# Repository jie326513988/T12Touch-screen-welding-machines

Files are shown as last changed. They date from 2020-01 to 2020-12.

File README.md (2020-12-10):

# 请注意！电流采样电路使用方法错误，电流不准，但不影响其他功能使用，修正版本正在制作！
# T12触屏焊台-Atmega328p-au核心
* 使用了[LCDWIKI_KBV、LCDWIKI_GUI、TouchScreen库](http://www.lcdwiki.com/zh/2.4inch_Arduino_Display)，感谢[LCDWIKI](http://www.lcdwiki.com)。
* Arduino Nano，触摸屏，降压电路都为模块拔插式，其他部分电路为贴片焊接，方便新手。
* 从30℃加热到400℃需16-20秒，稳定跳动温度±1℃，适配深圳头。
* 观看视频https://www.bilibili.com/video/av83184959
* 基本功能已经完善:
    *  触摸调节温度，30-400℃，3段一键温度
    *  使用虚拟数字键盘
    *  可菜单调节 单神经元PID，自主学习，控制精确（新增）
    *  可菜单调节 烙铁的休眠时间和休眠温度
    *  独立的室温采集芯片用于自动补偿T12温度
    *  屏幕校准，开机长按屏幕进入校准界面（新增）
    *  到达温度提示声，唤醒提示声，休眠提示声，触摸提示声（新增）
    *  eeprom保存数据
    *  INA19硬件真实电流采样
    *  内置看门狗防止死机引起意外
    *  未接手柄报警、烙铁温度超出读取范围报警、高压报警、过流报警、机内温度高温报警（新增）
    *  使用3项式公式计算的温度曲线，使用外部PT100探头精准调教的温度曲线
####   必读注意！！！
####   1：nano的bootloader使用看门狗有几率卡死，uno正常，先将nano刷成uno的引导再烧录程序
####   2：为了加快触摸的读取速度，需要修改以下内容，但有非常小的几率会误触
####      打开TouchScreen.cpp ,修改NUMSAMPLES 后面的数值为 20
####   3:一定要先刷入EEPROM，说明看程序第232行，首次使用记得校准屏幕（开机时长按屏幕，听到连续的提示声放开）
####   4:电流采样改用INA193芯片
####   5:使用可调DC-DC降压模块，调至6.5V使用，6.5V输入至nano自带线性稳压得到稳定的5V电压
####   6:不要更改t12_pwm_pin（nano 10号脚，2560 12号脚），此脚连接了内部定时器1的B通道，该通道需要输出61HZ和2048级pwm，内部定死，改了会有难以预料的后果
####   7:如果内存溢出，请看第2项说明改了就不会了
#### ---------------------------------------------------------------------------------------------
###  最新更新说明 V1.2.6 - 2020-09-24
#### 新增未接手柄报警、烙铁温度超出读取范围报警、高压报警、过流报警、机内温度高温报警
#### 当出现任意一个报警，主界面就会显示Error
#### 修复校准屏幕有几率无法保存数据的BUG
#### 再次校准温度曲线,使用3项式
#### 移除手动补偿设置(发现没什么用)
#### ---------------------------------------------------------------------------------------------
2020-09-22<br> v1.2.5 PMOS版本-需要UNO引导,修复手动补偿的BUG,修复pwm的一个BUG,使用PT100重新校准了温度曲线，缩小误差,开机前读取255次电压和室温<br>
2020-09-18<br> v1.2.4 PMOS版本-需要UNO引导,PWM控温精度改为2048级,加快超调回正时间,压榨内存<br>
2020-09-04<br> v1.2.3-仅限UNO引导使用,PID控温算法升级成“单神经元PID”，能自主学习以适配不同的刀头（同一厂家）和更加精准的控温。<br>
2020-09-02<br> v1.2.2-仅限UNO引导使用,修改温度显示策略，当温度稳定在10℃以内时，则显示每5次温度采集的平均温度，新增到达设定温度的提示声，取消从设置界面进入屏幕校准界面，只能从开机时长按屏幕任意地方进入并添加校准成功或失败的提示。<br>
2020-09-01<br> v1.2.1-仅限UNO引导使用,优化T12测量温度算法，使用睡眠模式进行ADC降噪读取，新增开机长按屏幕进入校准界面。<br>
2020-08-20<br> v1.2.0 PMOS版本-仅限UNO引导使用，新加手动温度补偿的功能，因nano内存不足需要刷成uno才能使用此版本。<br>
2020-07-12<br> v1.1.1 PMOS版本-Nano UNO可用，优化室温补偿的算法，优化读取电流的算法，优化键盘的算法，增加贴手感响应速度，新增开机读取电压和室温，重新测量了T12的温度曲线。<br>
2020-05-10<br> PMos版本已经测试完毕，mos正常发热0-50度，不会高到吓人，测量室温的NTC改为tc1047芯片，3D打印的外壳也重新设计并上传了。<br>
2020-02-17<br> NMOS的版本不再更新，即现在的版本（程序0.84和PCB1.3、1.4）。电路将大改一次，改用PMOS管改善发热问题，改用运放加0.1R的电阻检测电流，丢弃垃圾电流芯片。核心、5v电源和屏幕依旧使用拔插式。<br>
2020-02-17<br> v0.84，修改了主界面和设置界面的布局，使其更加对称顺眼。<br>
2020-02-14<br> V0.83，PWM输出修改成相位和频率校正模式，占空比控制精度提升一倍（0-511），并把频率降低至61HZ，烙铁发出的滴滴声大幅下降，频率提升到16khz时烙铁的滴滴声彻底听不见但MOS管发热严重并且控温效果差故不用高频PWM，喜欢滴滴声的可以用V0.82。<br>
2020-02-08<br>v0.82上线，增加测温的间隔，稍微提升一点加热效率。蜂鸣器的digitalWrite写法太占内存改为向端口输入引脚地址PINX写1来翻转状态bitWrite(PINB, 3, 1)，又节省74字节的内存，已用30606字节。修改了一下原理图和PCB，版本V1.4。优化sleep，当前温度低于设置的休眠温度时，到达休眠时间也存储当前温度。<br>
2020-02-07<br> 
上传原理图和能直接打板的文件，版本为V1.2。PCB我还想优化一下再放出，当然现在的版本也是可以用。<br>
2020-02-06<br>
v0.81 修复一个触屏校准的BUG。触摸加入一段限制算法降低屏幕自己点击自己的概率。电流测量加入一段判断算法，这样主界面就不会乱跳电流值了。<br>
2020-02-05<br>
v0.81版本，键盘触摸手感提升。<br>
2020-01-28 <br>
v0.81版本，修复了一个休眠的BUG，优化了温度测量，上传了3D打印件和成本清单。<br>
2020-01-24 <br>
v0.80版本，经过了8个小时的努力以及十几根头发的代价，又又又再一次压缩了Flash，还剩0.38%的空间，终于在nano/mini平台上加入屏幕校准功能。Uno平台还有5%，还可以美化一下UI。<br>
2020-01-22 <br>
v0.71版 新增坐标显示的开关，优化了flash，Mini还剩2%,Uno还剩7%,优化触摸读取速度，下一版本加入屏幕校准功能。<br>
2020-01-22 <br>
v0.7版，主界面新增一键到达设定温度的功能400/320/240。<br>
2020-01-20 <br>
v0.7版，增加软件过压过流过温保护，修正烙铁休眠唤醒不会回温的BUG，主界面美化一下，电路去掉了一个100欧的电阻，加热效率提升30%。<br>
2020-01-19 <br>
v0.6版上线，优化一些些内存，修改一下下菜单，增加了烙铁进入休眠的时间阈值和休眠的温度的菜单项，同样支持虚拟键盘修改数值和EEPROM。<br>
2020-01-16 <br>
优化了加热效率和控温稳定性。与设定值差10℃以上时，采样周期长，10℃以内，采样周期短。从30℃加热到260℃需15秒，稳定跳动温度3℃以内，通常为1℃。<br>
2020-01-14 <br>
终于实现了模拟键盘输入并可更改pid数值并储存在Eeprom中，有点小BUG但不影响使用。<br>
2020-01-13 <br>
初步实现稳定控温，从30℃加热到260℃需45秒，太久了。<br>
#### 引脚定义
LCD            D0  D1  D2  D3  D4  D5  D6  D7<br>
UNO/MINI/NANO  8   9   2   3   4   5   6   7<br>
LCDWIKI_KBV mylcd(ILI9341, A2, A1, 13, A0, 12);    //model,cs,cd,wr,rd,resett<br>
#define YP A2  // must be an analog pin, use "An" notation!<br>
#define XM A1  // must be an analog pin, use "An" notation!<br>
#define YM 9   // can be a digital pin<br>
#define XP 8   // can be a digital pin<br>
#define t12_temp_pin    A5                //T12温度读取引脚
#define sleep_pin       A3                //休眠状态读取引脚
#define ec_pin          A4                //电流读取引脚
#define volage_pin      A6                //电源电压读取引脚
#define tc1047_pin      A7                //tc1047读取引脚
#define t12_pwm_pin     10                //T12加热控制引脚
#define buzzer_pin      11                //蜂鸣器控制引脚
#### 电路简介
1.热电偶信号放大电路<br>
   使用AD8628（AD8605）轨到轨运算放大器，放大510倍，输入和输出均加有低通滤波器。<br>
2.功率输出电路<br>
   使用光耦和AOD4185场效应管组成的简单功率输出控制电路。<br>
3.检测电流电压电路<br>
   电流检测使用INA193芯片加0.05采样电阻，检测电流精度0.01A。<br>
   电压检测使用简单的分压电路测量，量程为0-42V，精度0.1V。<br>
4.供电电路<br>
   使用DCDC降压模块降至6.5V输入给Arduino Nano模块的VIN，上面有个5v稳压芯片，从而得到稳定的5V电压（要求纹波小，电压变动小）<br>
   24V电压使用的AC-DC24V4A成品电源，只要电压不超过24V电流大于3A即可。<br>
5.显示电路<br>
   使用2.4寸带触摸功能LCD屏幕模块，拔插式。提供显示功能和触摸功能。<br>
6.控制核心<br>
   使用Arduino Nano模块，核心为Atmel328p-AU,拔插式。<br>
 #### T12温度测量的方法及曲线拟合  
   * 因为每个厂家的T12内的热电偶都会有不同，所以不能使用常规的K/J/B型热电偶的分度表，除非T12厂家有给出
   * 准备一个能测500℃以上的测温设备，紧贴在T12的发热尖端，使用高温胶带绑紧
   * T12的热电偶电压经运算放大器510倍后再使用arduino测量T12的AD值，即T12热电偶的电压转换成数字量后的值
   * 使用pid算法加热T12，设置加热到的AD值为0-1000，每隔100个AD值记录一次温度
   * 记录得到AD值和对应的温度值后，使用EXCEL中的曲线拟合功能，拟合出一条三项式方程，此方程就是温度和AD关系的曲线
   * 有了此方程我们就能从T12当前的AD值计算出温度值
   * 本项目的方程 t12_temp = 0.0000001 * t12_ad * t12_ad * t12_ad - 0.00031185 * t12_ad * t12_ad + 0.64940017 * t12_ad + 15.945058;
   * 注意不同厂家的T12热电偶规格不同，更换厂家需要重新拟合一次曲线，本项目使用深圳头。
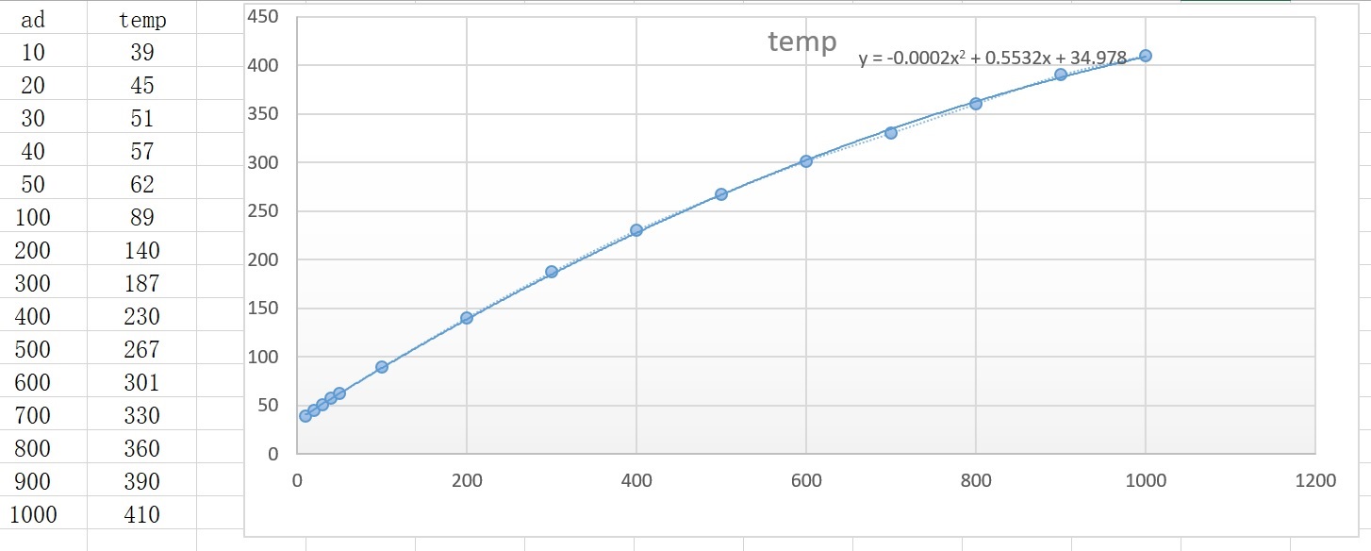
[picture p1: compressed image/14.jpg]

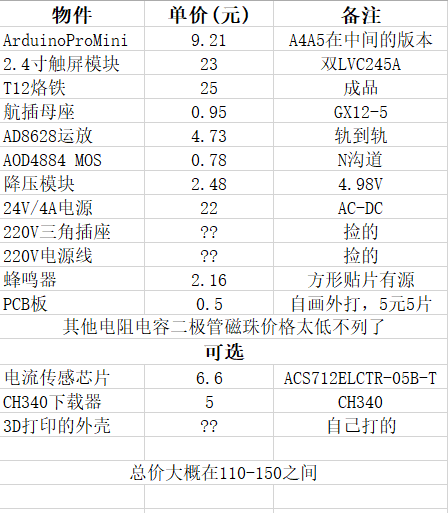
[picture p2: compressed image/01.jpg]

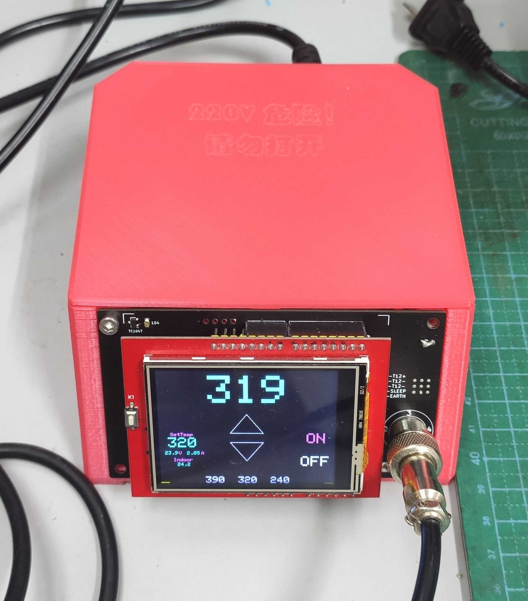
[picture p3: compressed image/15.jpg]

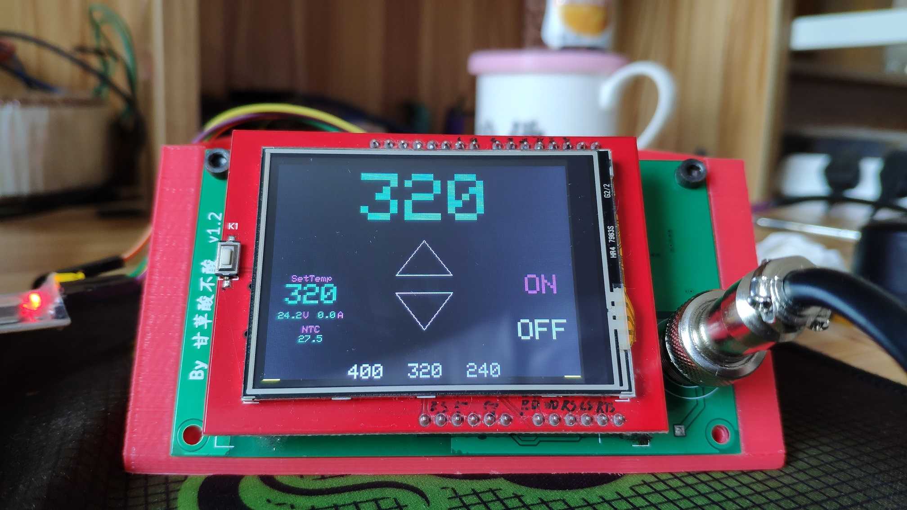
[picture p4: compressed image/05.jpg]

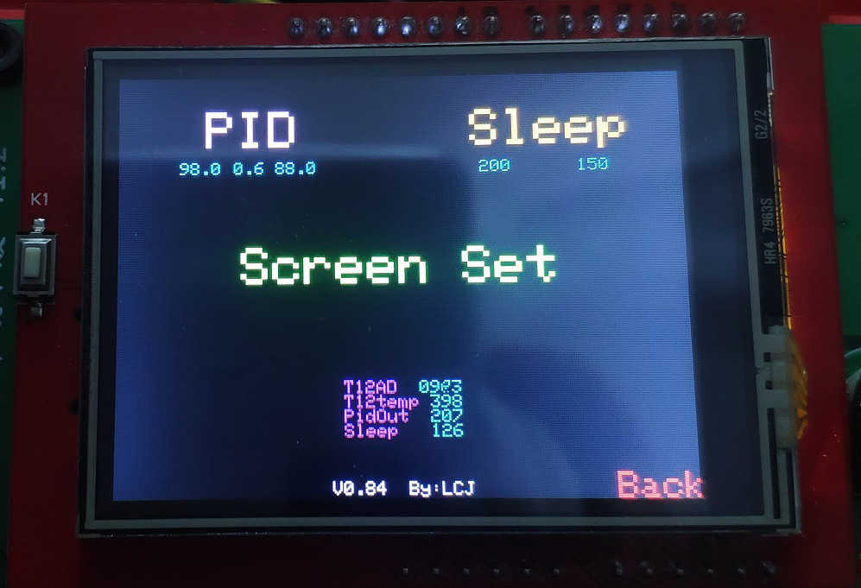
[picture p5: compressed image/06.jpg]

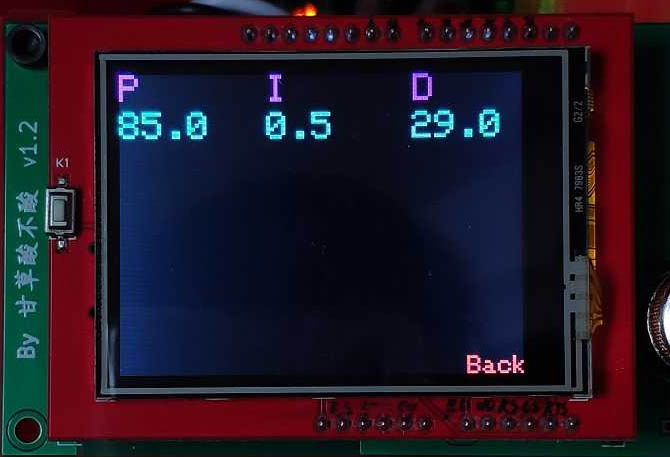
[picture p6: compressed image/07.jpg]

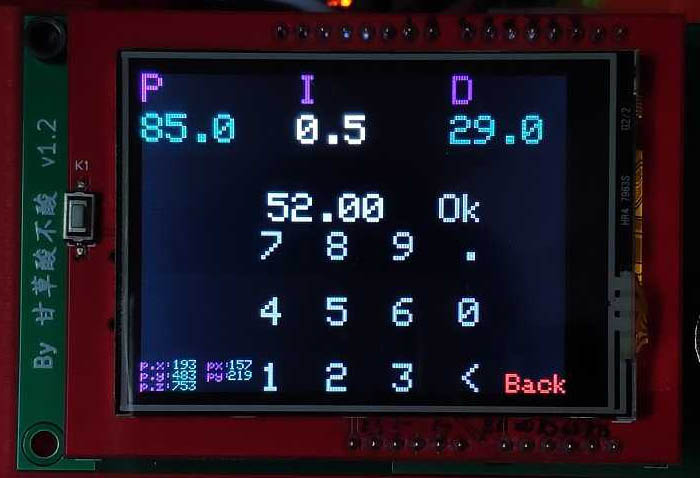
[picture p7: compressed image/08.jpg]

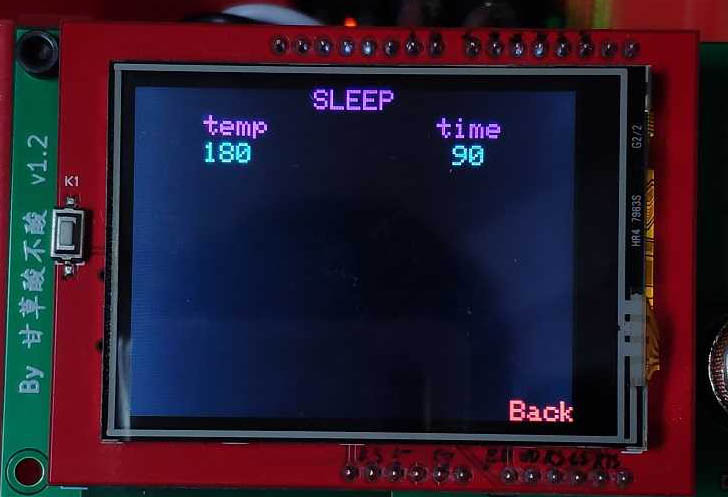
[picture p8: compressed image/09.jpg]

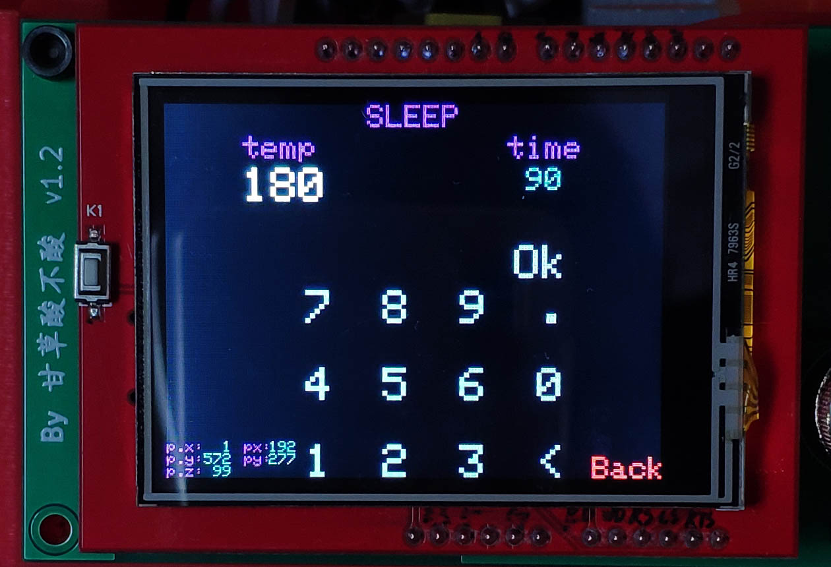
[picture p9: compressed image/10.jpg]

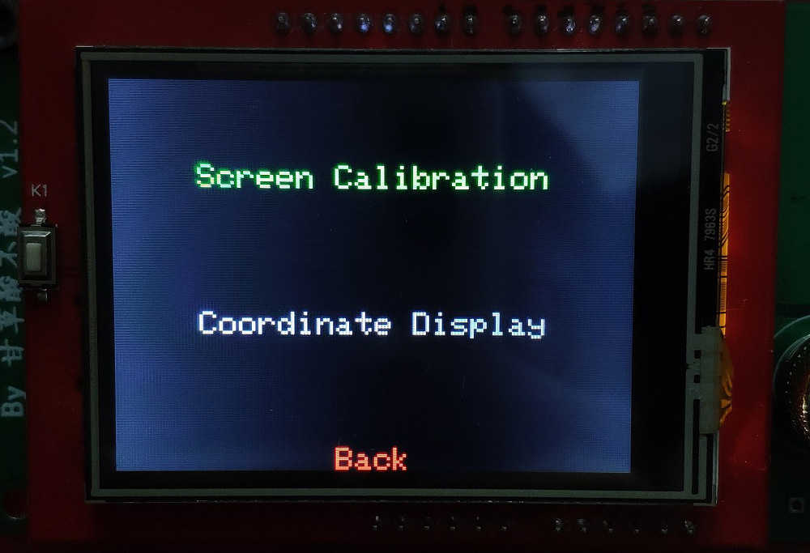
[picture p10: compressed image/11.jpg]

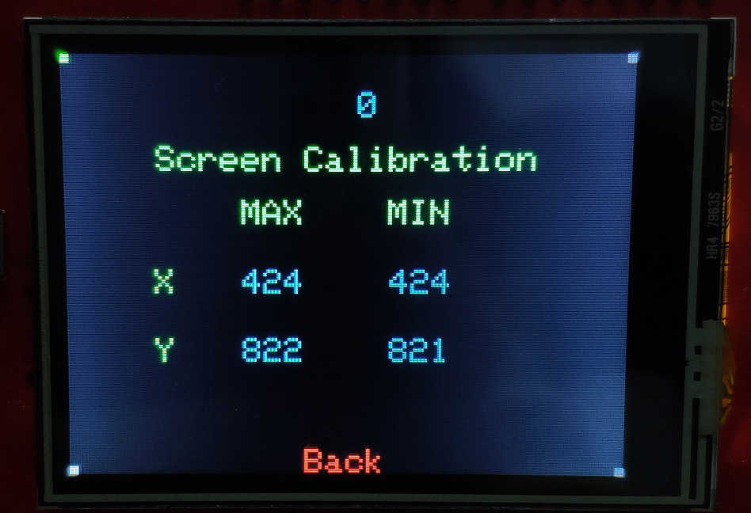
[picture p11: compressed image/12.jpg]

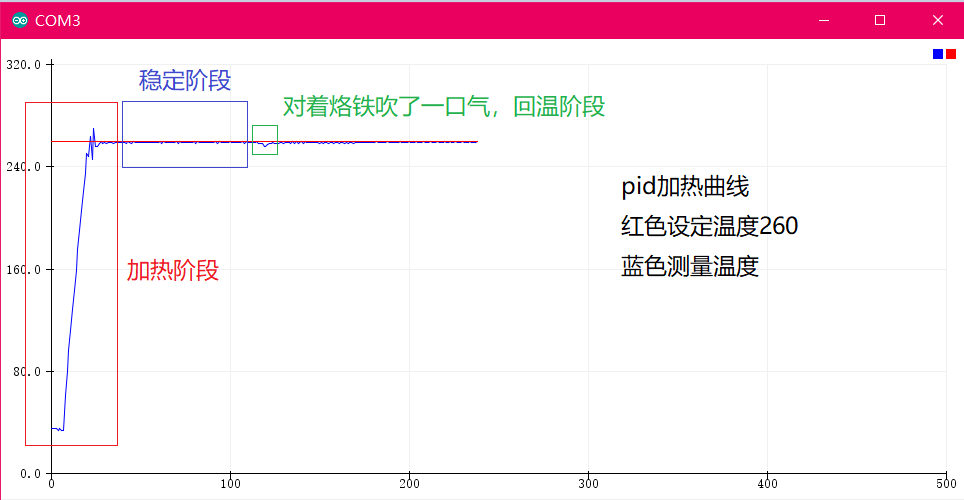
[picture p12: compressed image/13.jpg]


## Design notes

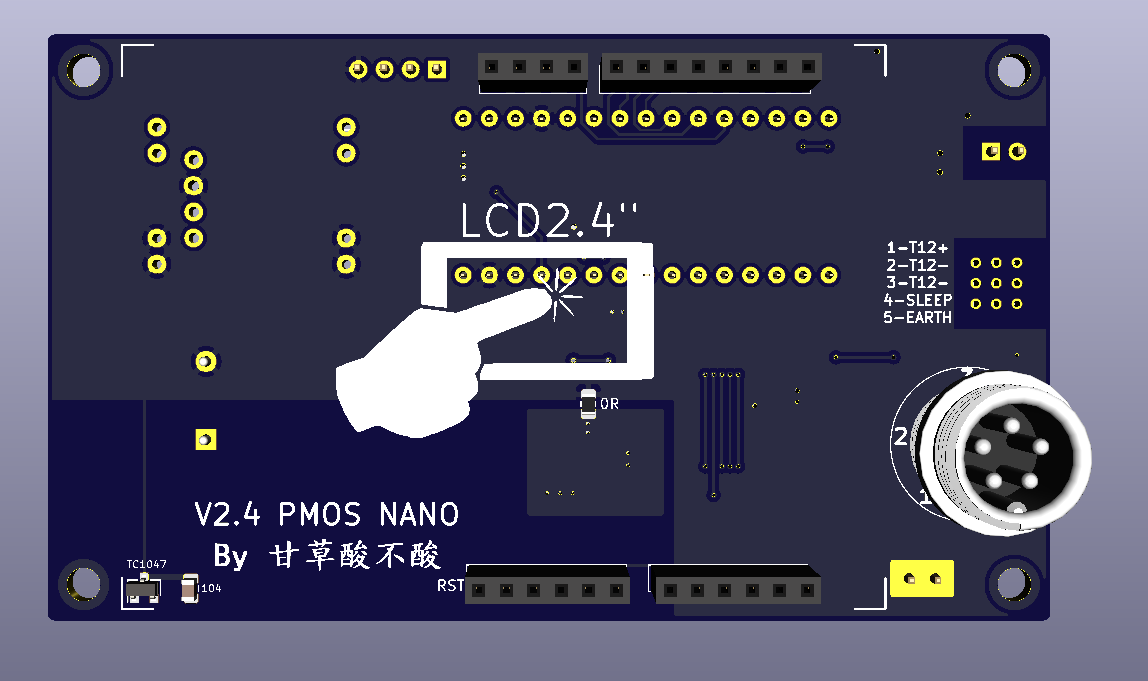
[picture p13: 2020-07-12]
PCB-V2.4/V2.4-PCB正面.png

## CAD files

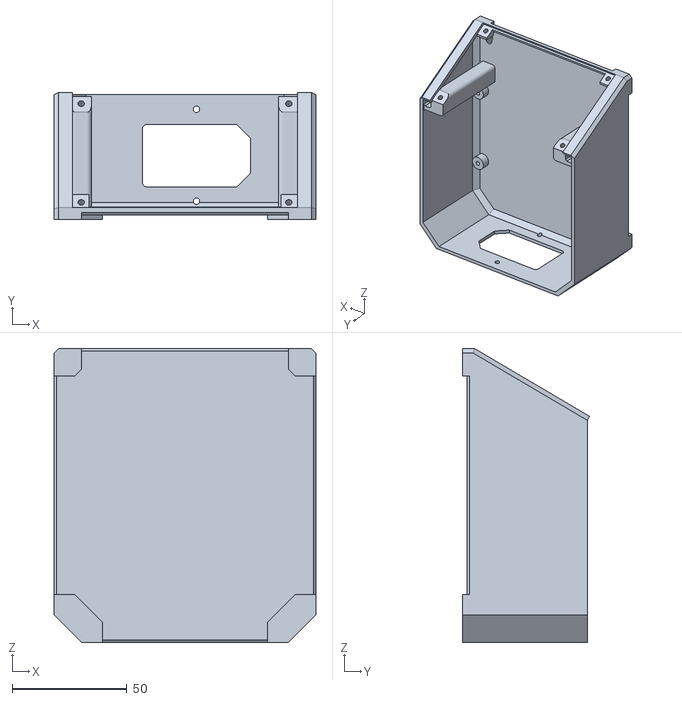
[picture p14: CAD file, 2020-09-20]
3D打印件/壳-改.STL
114.0 x 55.3 x 128.0

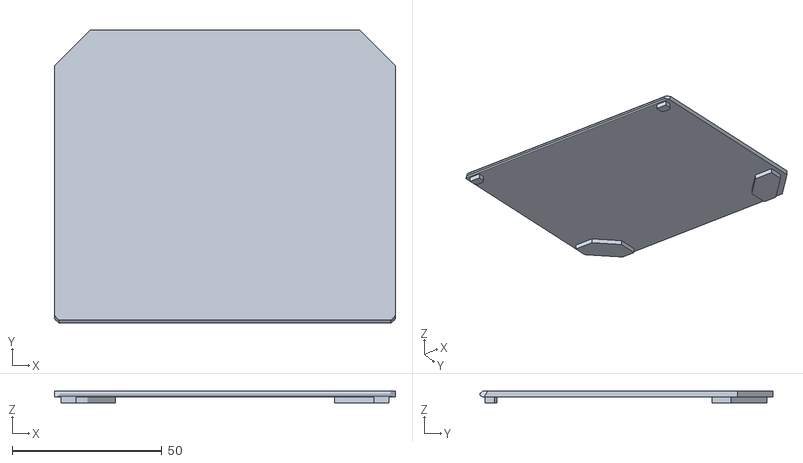
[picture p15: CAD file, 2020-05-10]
3D打印件/盖子_改.STL
114.0 x 98.1 x 4.00

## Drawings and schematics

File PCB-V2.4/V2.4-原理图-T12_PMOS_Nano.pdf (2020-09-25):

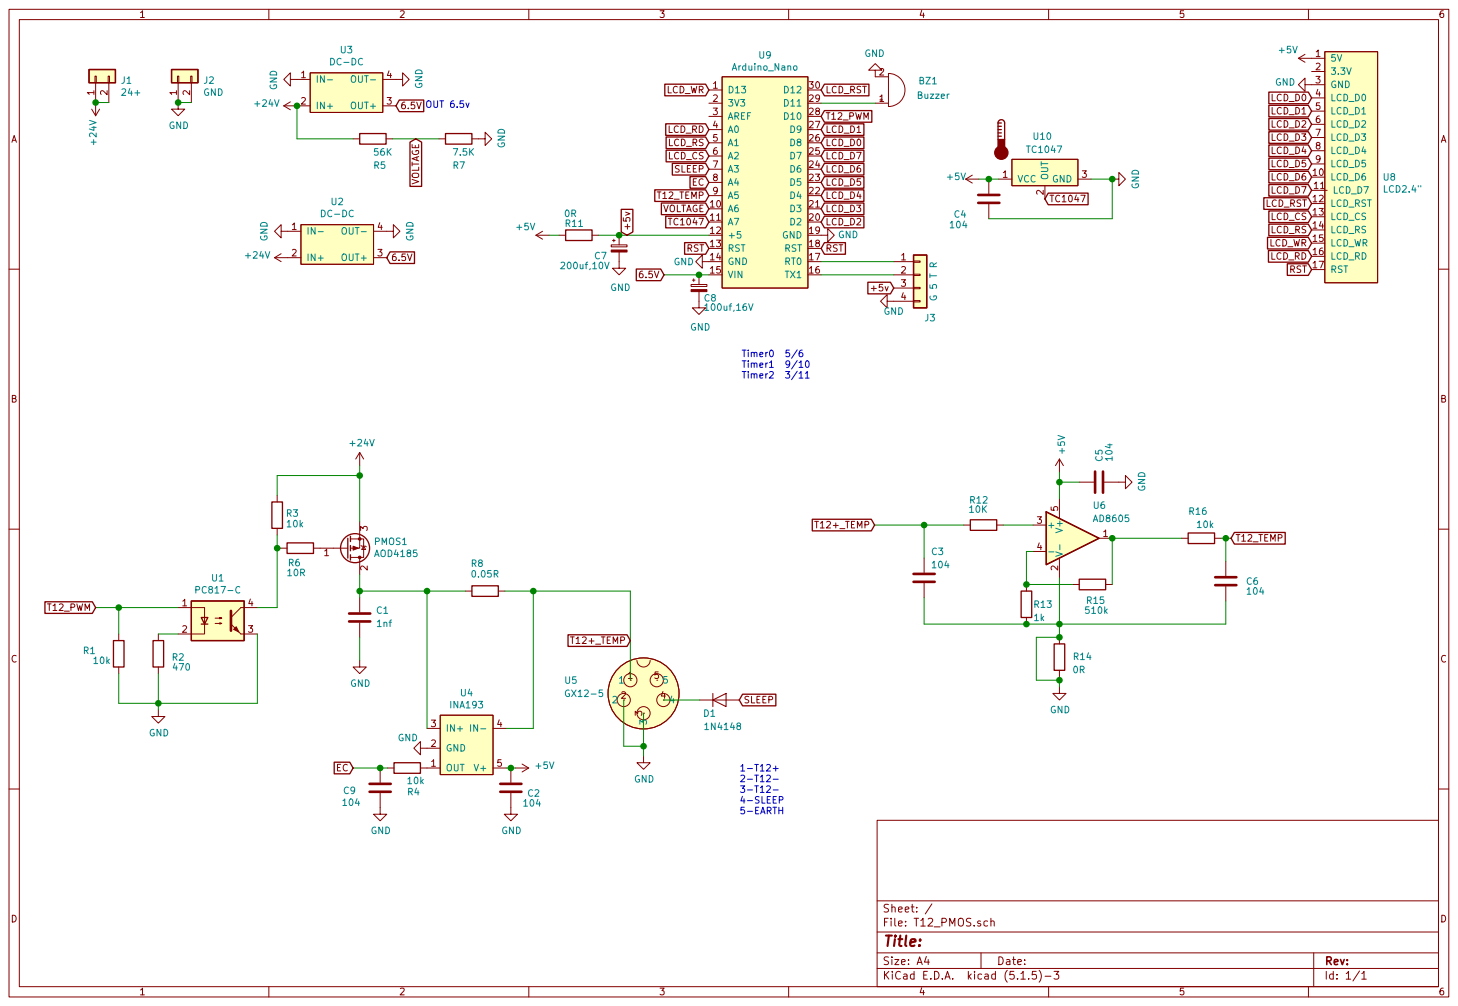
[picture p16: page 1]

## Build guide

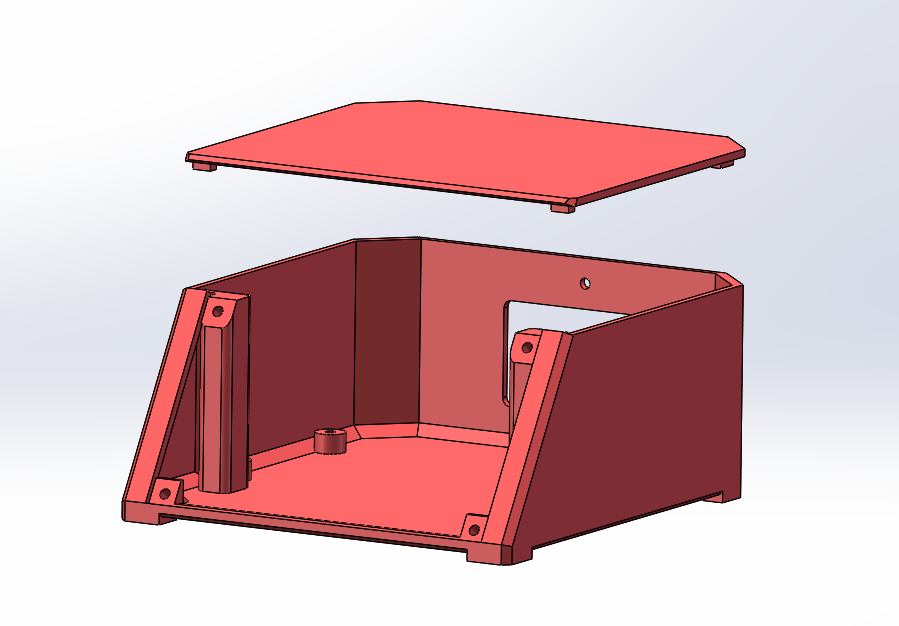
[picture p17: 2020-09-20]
3D打印件/装配体.png

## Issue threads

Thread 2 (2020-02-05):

Do you have a schematic for this project?

Timmy-Ti, 2020-02-05:
well...we need a schematic to creat our project...

jie326513988, 2020-02-05:
哪种示意图？你的英文我是用翻译软件看的，是PCB文件吗？

jie326513988, 2020-02-05:
> 好...我们需要一个示意图来创建我们的项目...

哪种示意图？你的英文我是用翻译软件看的，是PCB文件吗？

Timmy-Ti, 2020-02-06:
电路原理图

jie326513988, 2020-02-06:
> 电路原理图

原理图可以放出，但pcb图还需完善

jie326513988, 2020-02-06:
> 电路原理图

> 电路原理图

还需完善，以后会放出，但你可以参考这篇文章http://jurgis.me/2017/05/25/diy-t12-soldering-station/

Timmy-Ti, 2020-02-06:
万分感谢！

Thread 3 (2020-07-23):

T12Touch-screen-welding-machines

JHS1211, 2020-07-23:
您好，您的这个焊台很漂亮，我也做了一个，但是给其刷程序始终不成功，请问您，您的HEX固件是用什么软件刷的？希望得到您的帮助，谢谢。

jie326513988, 2020-07-23:
使用Arduino官方的ied编译上传，但要注意版本所对应的板子类型。如果你是用的nano/mini的板子请刷v1.1.1，uno的板子就可以刷v1.2.0。如果你需要刷bootloader网上有许多教程。但仍需注意先刷一遍eeprom，在注释掉刷入正常程序。

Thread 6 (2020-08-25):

关于适配各种品牌的T12烙铁头

drzzzf, 2020-08-25:
你好~很感谢你开源了那么完美的一个产品~
我也很想diy一台这样的焊台，不过我现在有个实际使用中的需求。
就是我有各种品牌的T12烙铁头，使用中发现，各个品牌的热电偶参数天差地别，导致在相同温度设定的情况下，实际温度会差很多。
所以我想可否增加一个，在更换烙铁头的时候，可以选择烙铁头的品牌的功能。各个品牌的热电偶的公式，可以自己去根据实际测试了事先写道代码里去。
在实际使用中，如果检测到烙铁头拔出，再插入，系统自动会让我们选择事先录入的烙铁头品牌。
这样就能兼容何种品牌的烙铁头并且可以获取正确的温度控制，感觉这样会是一个非常完美的设计~
谢谢！
